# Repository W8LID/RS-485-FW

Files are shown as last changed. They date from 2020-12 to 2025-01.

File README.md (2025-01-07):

# RS-485-FW
An RS-485 FeatherWing for the Adafruit Feather system.

RS-485-FW-render

The RS-485 FeatherWing provides level shifting of the TTL UART on Adafruit Feather type development boards. This board is based on the Maxim MAX3485 transceiver. It also provides an automatic direction control circuit so as to not require any additional GPIO pins for direction control.

This board is designed with minimal components in mind to keep complexity and cost to a minimum. Component footprints were chosen to allow for hand soldering and no special equipment required for assembly.

Note: The 4.7kΩ bias resistors (R1 & R3) should only be populated on a single device on an RS-485 bus. That is, if attempting to communicate between two RS-485 FeatherWings on the same bus, only populate R1 & R3 on a single FeatherWing.

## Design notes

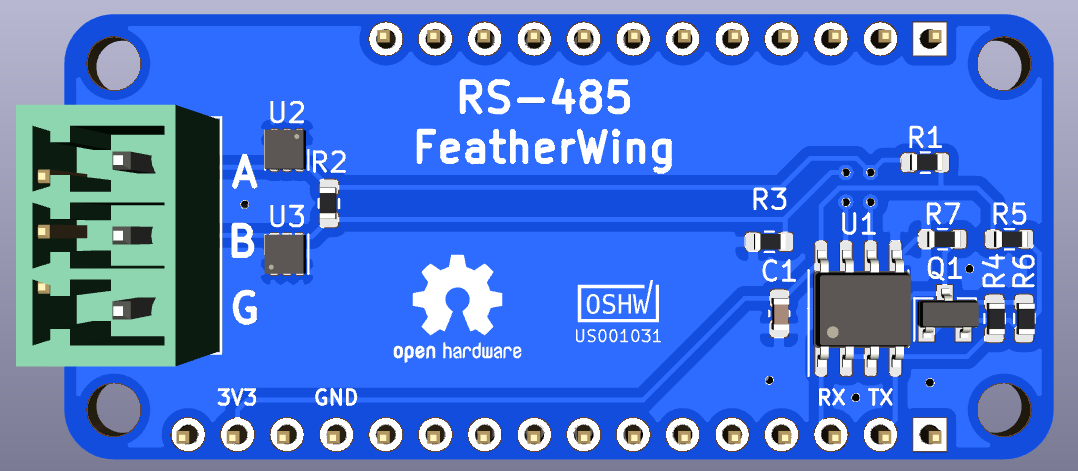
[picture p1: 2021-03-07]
Images/RS-485-FW-render.png

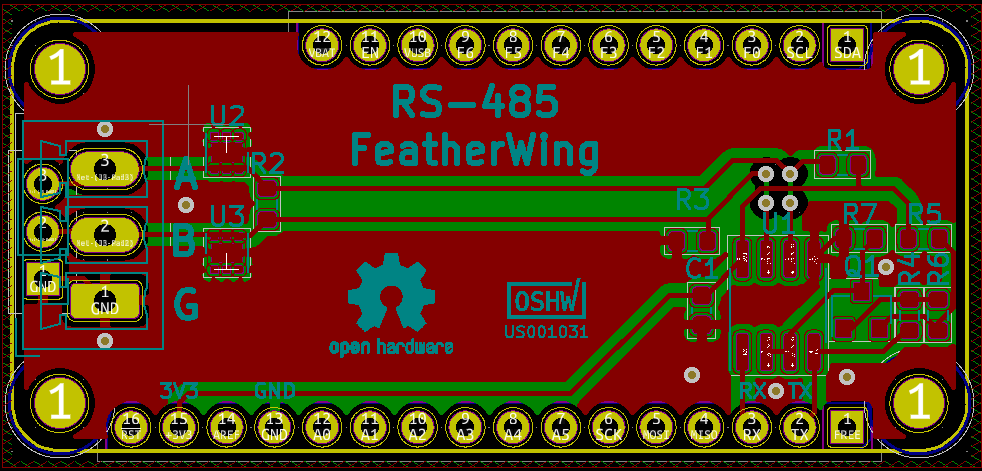
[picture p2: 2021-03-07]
Images/RS-485-FW-PCB.png

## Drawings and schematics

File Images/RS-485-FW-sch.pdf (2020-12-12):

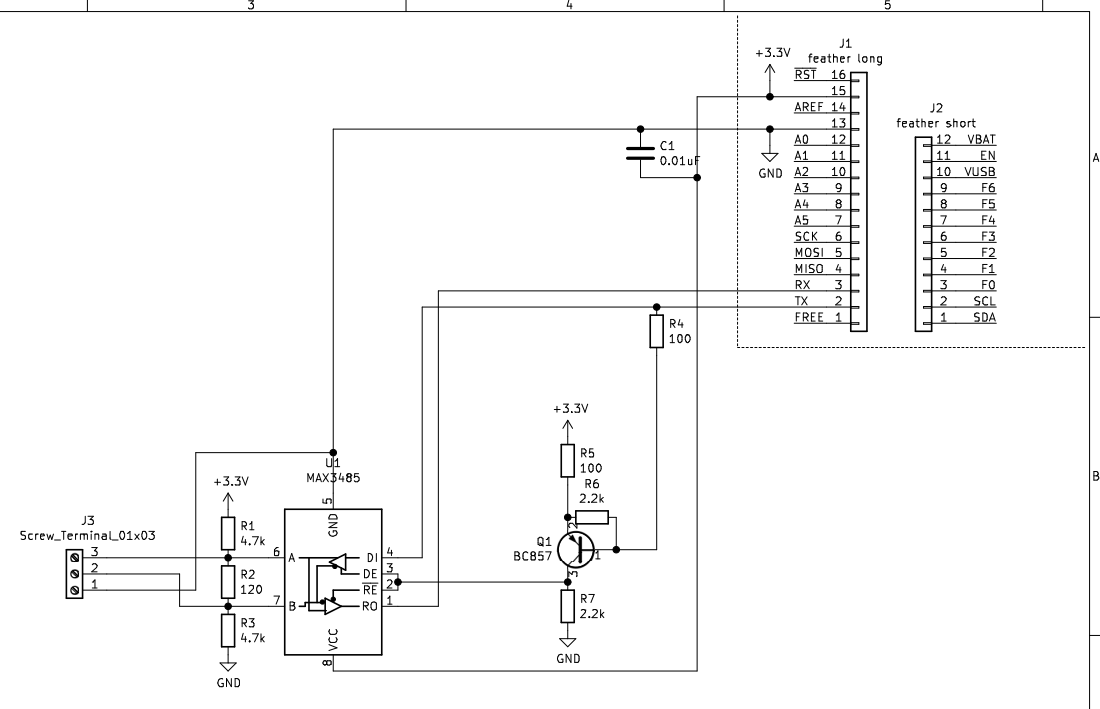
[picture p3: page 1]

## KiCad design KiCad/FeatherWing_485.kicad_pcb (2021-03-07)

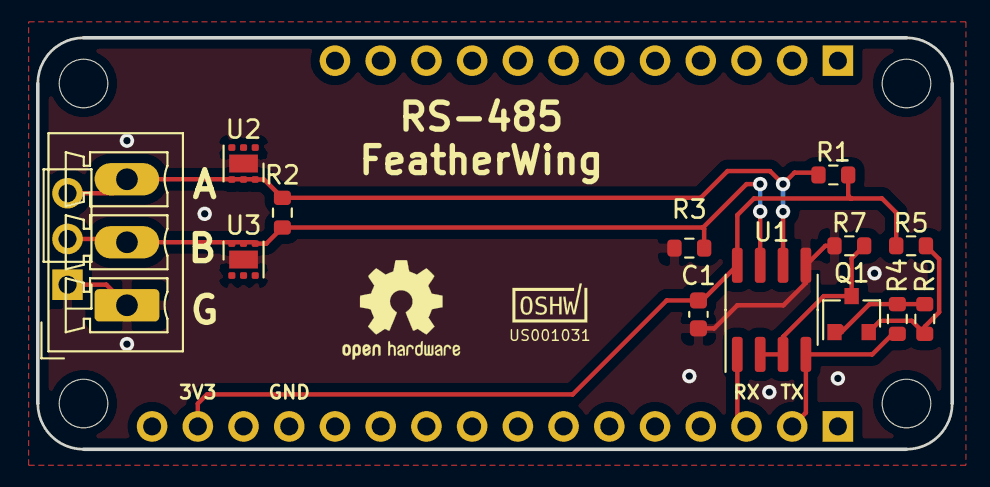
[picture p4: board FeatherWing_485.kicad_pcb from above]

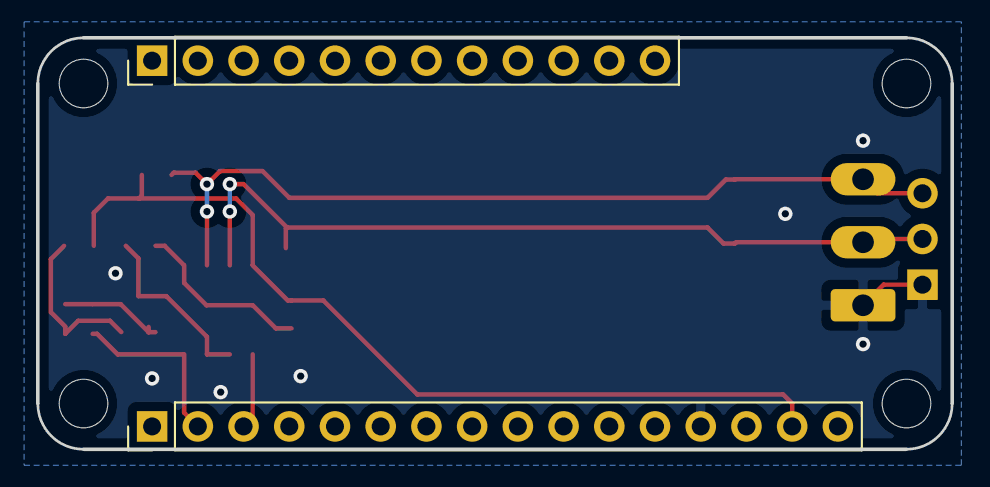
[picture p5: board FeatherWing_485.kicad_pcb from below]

Board: 2 copper layers, 50.8 x 22.9 mm, 17 parts (2 on the bottom side), 9 nets.

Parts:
C1: 0.01uF; C_0603_1608Metric
J1: feather long; PinHeader_1x16_P2.54mm_Vertical
J2: feather short; PinHeader_1x12_P2.54mm_Vertical
J3: Screw_Terminal_01x03; PhoenixContact_MCV_1,5_3-G-3.5_1x03_P3.50mm_Vertical
J4: Conn_01x03_Male; PinHeader_1x03_P2.54mm_Vertical
OSHW_Mono_0.1_Scale: US001031; OSHW_Mono_0.1_Scale
Q1: BC857; SOT-23
R1, R3: 4.7k; R_0603_1608Metric
R2: 120; R_0603_1608Metric
R4, R5: 100; R_0603_1608Metric
R6, R7: 2.2k; R_0603_1608Metric
U1: MAX3485; SOIC-8_3.9x4.9mm_P1.27mm
U2, U3: TVS0500DRV; WSON-6-1EP_2x2mm_P0.65mm_EP1x1.6mm

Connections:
+3V3: C1.2, J1.15, R1.1, R5.1, U1.8
/RX: J1.3, U1.1
/TX: J1.2, R4.1, U1.4
GND: C1.1, J1.13, J3.1, J4.1, R3.2, R7.2, U1.5, U2.1, U2.2, U2.3, U2.7, U3.1, U3.2, U3.3, U3.7
unnamed: J3.2, J4.2, R2.2, R3.1, U1.7, U3.4, U3.5, U3.6
unnamed: J3.3, J4.3, R1.2, R2.1, U1.6, U2.4, U2.5, U2.6
unnamed: Q1.1, R4.2, R6.1
unnamed: Q1.2, R5.2, R6.2
unnamed: Q1.3, R7.1, U1.2, U1.3

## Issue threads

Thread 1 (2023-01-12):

U2 and U3 messing from BOM and Schematics

hattesen, 2023-01-12:
It seems that the schematics (image) and BOM are missing U2 and U3, which are present on the PCB (image), and on the production boards.
it seems to be protection devices on the RS-485 bus.
Any chance to have the files updated to reflect the product currently being shipped?

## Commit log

2020-12-12 Add schematic and PCB renders.
    Add schematic and PCB PDF files as well as a 3D PCB render image.
2020-12-12 Add KiCad files.
    Add KiCad projecct files.
    [FeatherWing_485.kicad_pcb, FeatherWing_485.sch]
2020-12-12 Fix footprint
    Use 0603 footprint for C1
    [FeatherWing_485.kicad_pcb, FeatherWing_485.sch]
2020-12-12 Add BOM
    Add BOM generated by KiCad
2020-12-12 Update render
    Changed C1 footprint
2020-12-12 Updated render
    Changed footprint of C1
2020-12-13 Update PCB
2020-12-13 Updated PCB
    Add copper fill.
    [FeatherWing_485.kicad_pcb]
2021-03-07 Update kicad files
    Update for revised PCB
    [FeatherWing_485.kicad_pcb, FeatherWing_485.sch]
2021-03-07 Delete PDF version of PCB
    Delete PDF in exchange for PNG
2021-03-07 Update images
    update images for PCB
2021-03-07 Update README.md
    Add board render image
